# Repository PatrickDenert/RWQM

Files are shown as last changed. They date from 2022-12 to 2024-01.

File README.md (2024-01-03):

Abstract- Many water sources in the world are currently contaminated or at risk of
contamination. The purpose of this system is to allow for the remote monitoring of
water sources in order to preserve the health of many communities. Allowing remote
monitoring allows for faster results and constant monitoring of water quality.

For a full documentation of the project then you can read the Remote Water Quality Monotor report pdf listed in the repository.

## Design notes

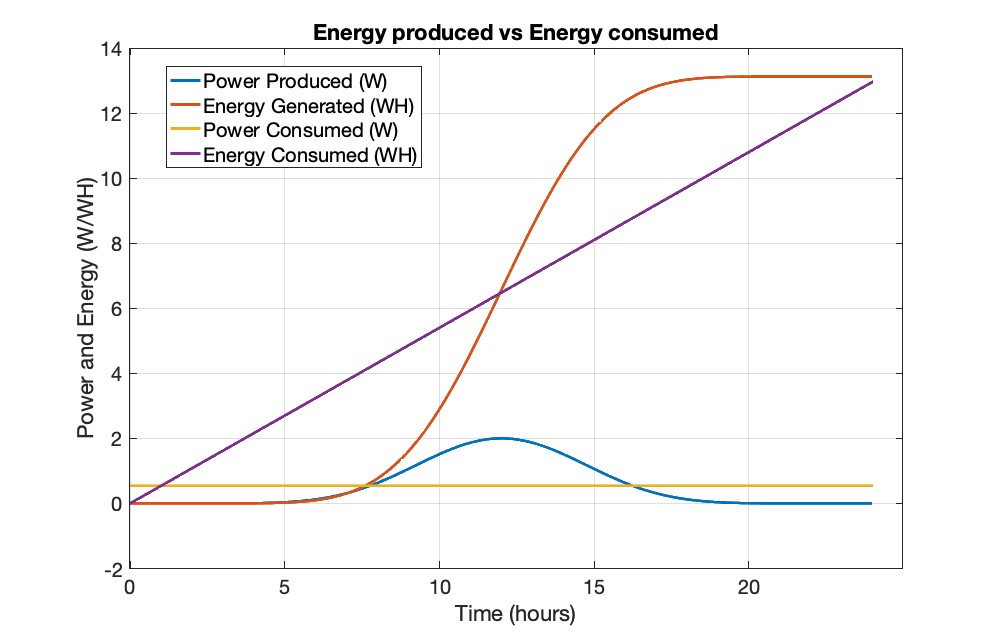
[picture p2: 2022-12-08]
assets/energy.jpg

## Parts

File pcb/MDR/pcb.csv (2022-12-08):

Source: | /Users/dave/Documents/school/sdp/pcb/MDR/pcb.kicad_sch
Date: | Thursday, November 10, 2022 at 03:40:49 PM
Tool: | Eeschema (6.0.7-1)-1
Generator: | /Applications/KiCad/KiCad.app/Contents/SharedSupport/plugins/bom_csv_grouped_by_value.py
Component Count: | 13
Individual Components:
Item | Qty | Reference(s) | Value | LibPart | Footprint | Datasheet
 |  | C1 | 0.1uF | Device:C | Capacitor_SMD:C_1206_3216Metric_Pad1.33x1.80mm_HandSolder | ~
 |  | C2 | 0.1uF | Device:C | Capacitor_SMD:C_1206_3216Metric_Pad1.33x1.80mm_HandSolder | ~
 |  | C3 | 0.1uF | Device:C | Capacitor_SMD:C_1206_3216Metric_Pad1.33x1.80mm_HandSolder | ~
 |  | C4 | 22pF | Device:C | Capacitor_SMD:C_1206_3216Metric_Pad1.33x1.80mm_HandSolder | ~
 |  | C5 | 22pF | Device:C | Capacitor_SMD:C_1206_3216Metric_Pad1.33x1.80mm_HandSolder | ~
 |  | J1 | 1x3f Tmp Sens | Connector:Conn_01x03_Male | Connector_PinSocket_2.54mm:PinSocket_1x03_P2.54mm_Vertical | ~
 |  | J2 | 1x4f Screen | Connector:Conn_01x04_Female | Connector_PinSocket_2.54mm:PinSocket_1x04_P2.54mm_Vertical | ~
 |  | J3 | 1x8f Digital Pin Headers | Connector:Conn_01x08_Female | Connector_PinSocket_2.54mm:PinSocket_1x08_P2.54mm_Vertical | ~
 |  | J4 | 1x2f LED | Connector:Conn_01x02_Female | Connector_PinHeader_2.54mm:PinHeader_1x02_P2.54mm_Vertical | ~
 |  | J5 | 1x3f tmp switch | Connector:Conn_01x03_Female | Connector_PinSocket_2.54mm:PinSocket_1x03_P2.54mm_Vertical | ~
 |  | J6 | 1x2F 5V in | Connector:Conn_01x02_Female | Connector_PinHeader_2.54mm:PinHeader_1x02_P2.54mm_Vertical | ~
 |  | U1 | ATmega328-P | MCU_Microchip_ATmega:ATmega328-P | Package_DIP:DIP-28_W7.62mm_Socket | http://ww1.microchip.com/downloads/en/DeviceDoc/ATmega328_P%20AVR%20MCU%20with%20picoPower%20Technology%20Data%20Sheet%2040001984A.pdf
 |  | Y1 | 16MHz | Device:Crystal | Crystal:Crystal_SMD_3225-4Pin_3.2x2.5mm | ~
Collated Components:
Item | Qty | Reference(s) | Value | LibPart | Footprint | Datasheet
1 | 3 | C1, C2, C3 | 0.1uF | Device:C | Capacitor_SMD:C_1206_3216Metric_Pad1.33x1.80mm_HandSolder | ~
2 | 2 | C4, C5 | 22pF | Device:C | Capacitor_SMD:C_1206_3216Metric_Pad1.33x1.80mm_HandSolder | ~
3 | 1 | J1 | 1x3f Tmp Sens | Connector:Conn_01x03_Male | Connector_PinSocket_2.54mm:PinSocket_1x03_P2.54mm_Vertical | ~
4 | 1 | J2 | 1x4f Screen | Connector:Conn_01x04_Female | Connector_PinSocket_2.54mm:PinSocket_1x04_P2.54mm_Vertical | ~
5 | 1 | J3 | 1x8f Digital Pin Headers | Connector:Conn_01x08_Female | Connector_PinSocket_2.54mm:PinSocket_1x08_P2.54mm_Vertical | ~
6 | 1 | J4 | 1x2f LED | Connector:Conn_01x02_Female | Connector_PinHeader_2.54mm:PinHeader_1x02_P2.54mm_Vertical | ~
7 | 1 | J5 | 1x3f tmp switch | Connector:Conn_01x03_Female | Connector_PinSocket_2.54mm:PinSocket_1x03_P2.54mm_Vertical | ~
8 | 1 | J6 | 1x2F 5V in | Connector:Conn_01x02_Female | Connector_PinHeader_2.54mm:PinHeader_1x02_P2.54mm_Vertical | ~
9 | 1 | U1 | ATmega328-P | MCU_Microchip_ATmega:ATmega328-P | Package_DIP:DIP-28_W7.62mm_Socket | http://ww1.microchip.com/downloads/en/DeviceDoc/ATmega328_P%20AVR%20MCU%20with%20picoPower%20Technology%20Data%20Sheet%2040001984A.pdf
10 | 1 | Y1 | 16MHz | Device:Crystal | Crystal:Crystal_SMD_3225-4Pin_3.2x2.5mm | ~

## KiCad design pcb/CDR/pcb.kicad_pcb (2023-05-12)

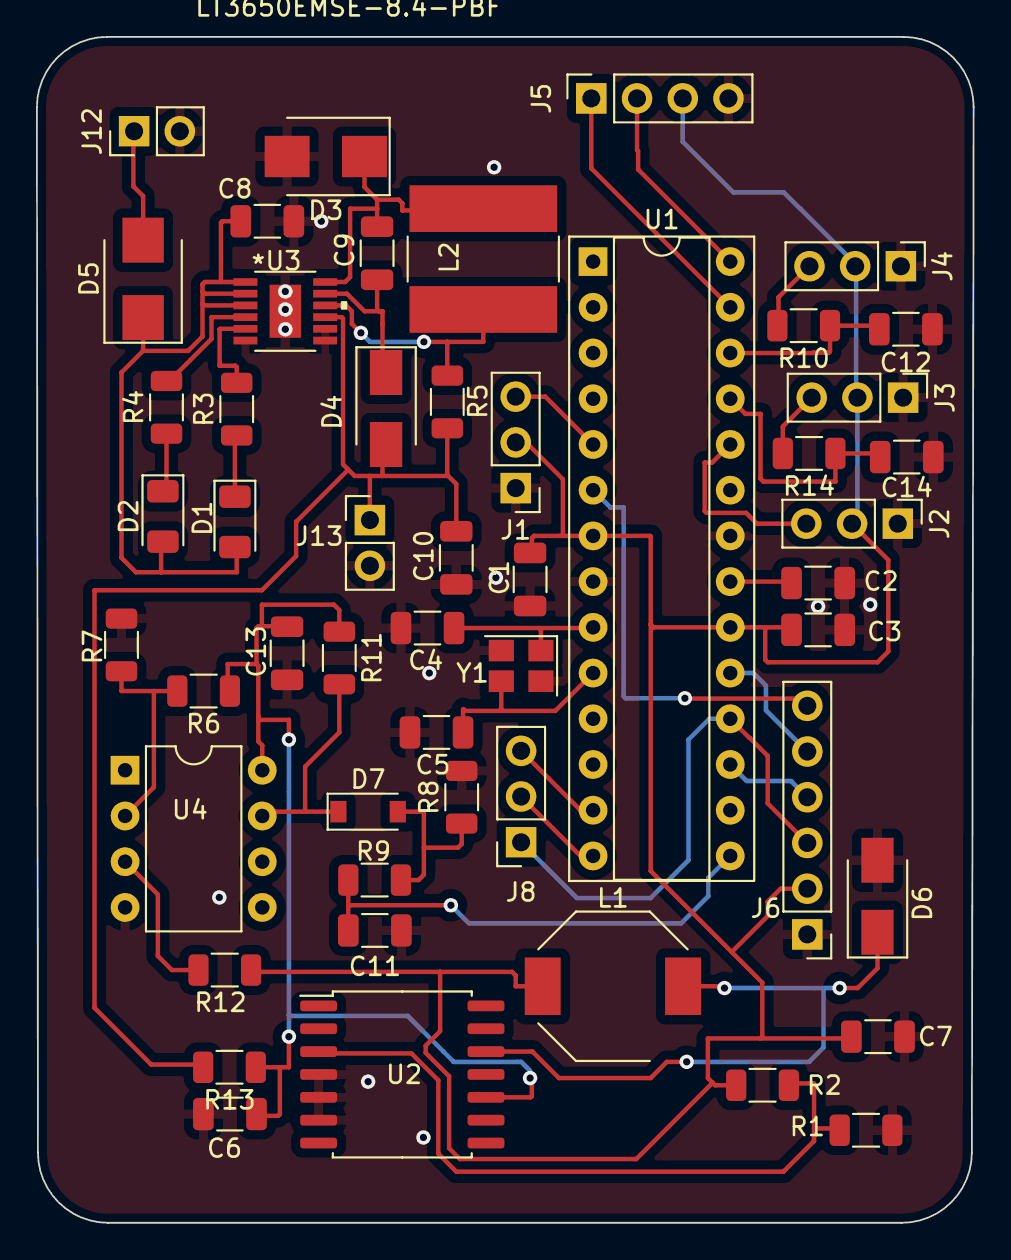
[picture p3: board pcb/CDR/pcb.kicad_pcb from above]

Board: 2 copper layers, 52.0 x 65.9 mm, 51 parts (0 on the bottom side), 37 nets.

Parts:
C1, C2, C3: 0.1uF; C_1206_3216Metric
C4, C5: 22pF; C_1206_3216Metric
C6: 22uF; C_1206_3216Metric
C7: 220uF; C_1206_3216Metric
C8, C10, C11, C12, C14: 10uF; C_1206_3216Metric
C9, C13: 1uF; C_1206_3216Metric
D1: Red; D_1206_3216Metric
D2: Green; D_1206_3216Metric
D3, D5: CMPSH3-40MA; D_SMB
D4: CMPSH1-4; D_SMA
D6: 11DQ06; D_SMA
D7: 1V; D_SOD-123
J1, J2, J3, J4: Conn_01x03_Male; PinHeader_1x03_P2.54mm_Vertical
J5: Conn_01x04_Female; PinSocket_1x04_P2.54mm_Vertical
J6: SD Card Reader; PinHeader_1x06_P2.54mm_Vertical
J8: cell data headers; PinSocket_1x03_P2.54mm_Vertical
J12: V Solar; PinHeader_1x02_P2.54mm_Vertical
J13: V batt; PinHeader_1x02_P2.54mm_Vertical
L1: 330 uH; L_Bourns-SRU8028_8.0x8.0mm
L2: 10uH; L_Bourns-SRN8040_8x8.15mm
R1: 1K; R_1206_3216Metric
R2: 3.1k; R_1206_3216Metric
R3, R4: 5.1k; R_1206_3216Metric
R5: 0.05; R_1206_3216Metric
R6: 100k; R_1206_3216Metric
R7: 220k; R_1206_3216Metric
R8: 50k; R_1206_3216Metric
R9: 160; R_1206_3216Metric
R10, R14: 0/160; R_1206_3216Metric
R11: 1k; R_1206_3216Metric
R12, R13: 0; R_1206_3216Metric
U1: ATmega328-P; DIP-28_W7.62mm_Socket
U2: LM2574HVM-12; SOIC-14W_7.5x9mm_P1.27mm
U3: LT3650EMSE-8.4-PBF
U4: LM311; DIP-8_W7.62mm
Y1: 16MHz; Crystal_SMD_TXC_7M-4Pin_3.2x2.5mm

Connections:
GND: C1.2, C2.2, C3.1, C4.1, C5.1, C6.2, C7.2, C8.2, C10.2, C11.2, C12.1, C13.1, C14.1, D3.2 (A), D6.2 (A), J1.1, J2.1, J3.1, J4.1, J5.4, J6.1, J12.2, J13.2, R1.1, R7.1, R8.2, U1.8 (GND), U1.22 (GND), U2.4 (SGND), U2.5 (~ON/OFF), U2.6 (PGND), U3.6 (TIMER), U3.7 (RNG/SS), U3.8 (NTC), U3.EPAD, U4.4 (V-), Y1.2, Y1.4
unnamed: C2.1, U1.21 (AREF)
unnamed: C4.2, U1.9 (XTAL1/PB6), Y1.1
unnamed: C5.2, U1.10 (XTAL2/PB7), Y1.3
unnamed: C8.1, D1.2 (A), D2.2 (A), D5.1 (K), U3.1 (VIN), U3.2 (CLP), U3.3 (*SHDN)
unnamed: C9.1, D3.1 (K), L2.2, U3.12 (SW)
unnamed: C9.2, D4.1 (K), U3.11 (BOOST)
unnamed: C10.1, D4.2 (A), J13.1, R5.2, R13.2, U3.9 (BAT)
unnamed: C11.1, R9.2, U1.15 (PB1)
unnamed: C12.2, R10.1, U1.26 (PC3)
unnamed: C6.1, C13.2, R6.1, R11.1, R13.1, U2.10 (VIN), U4.8 (V+)
unnamed: C14.2, R14.1, U1.25 (PC2)
unnamed: D1.1 (K), R3.1
unnamed: D2.1 (K), R4.1
unnamed: D5.2 (A), J12.1
unnamed: D6.1 (K), L1.1, U2.12 (OUT)
unnamed: D7.1 (K), R11.2, U4.7
unnamed: D7.2 (A), R8.1, R9.1
unnamed: J1.3, U1.5 (PD3)
unnamed: J2.3, U1.24 (PC1)
unnamed: J3.3, R14.2
unnamed: J4.3, R10.2
unnamed: J5.1, U1.27 (PC4)
unnamed: J5.2, U1.28 (PC5)
unnamed: J6.3, J8.1, U1.18 (PB4)
unnamed: J6.4, U1.17 (PB3)
unnamed: J6.5, U1.19 (PB5)
unnamed: J6.6, U1.6 (PD4)
unnamed: J8.2, U1.14 (PB0)
unnamed: J8.3, U1.13 (PD7)
unnamed: L2.1, R5.1, U3.10 (SENSE)
unnamed: R1.2, R2.2, U2.3 (FB)
unnamed: R3.2, U3.5 (*FAULT)
unnamed: R4.2, U3.4 (*CHRG)
unnamed: R6.2, R7.2, U4.2 (+)
unnamed: R12.1, U4.3 (-)
VCC: C1.1, C3.2, C7.1, J1.2, J2.2, J3.2, J4.2, J5.3, J6.2, L1.2, R2.1, R12.2, U1.7 (VCC), U1.20 (AVCC)

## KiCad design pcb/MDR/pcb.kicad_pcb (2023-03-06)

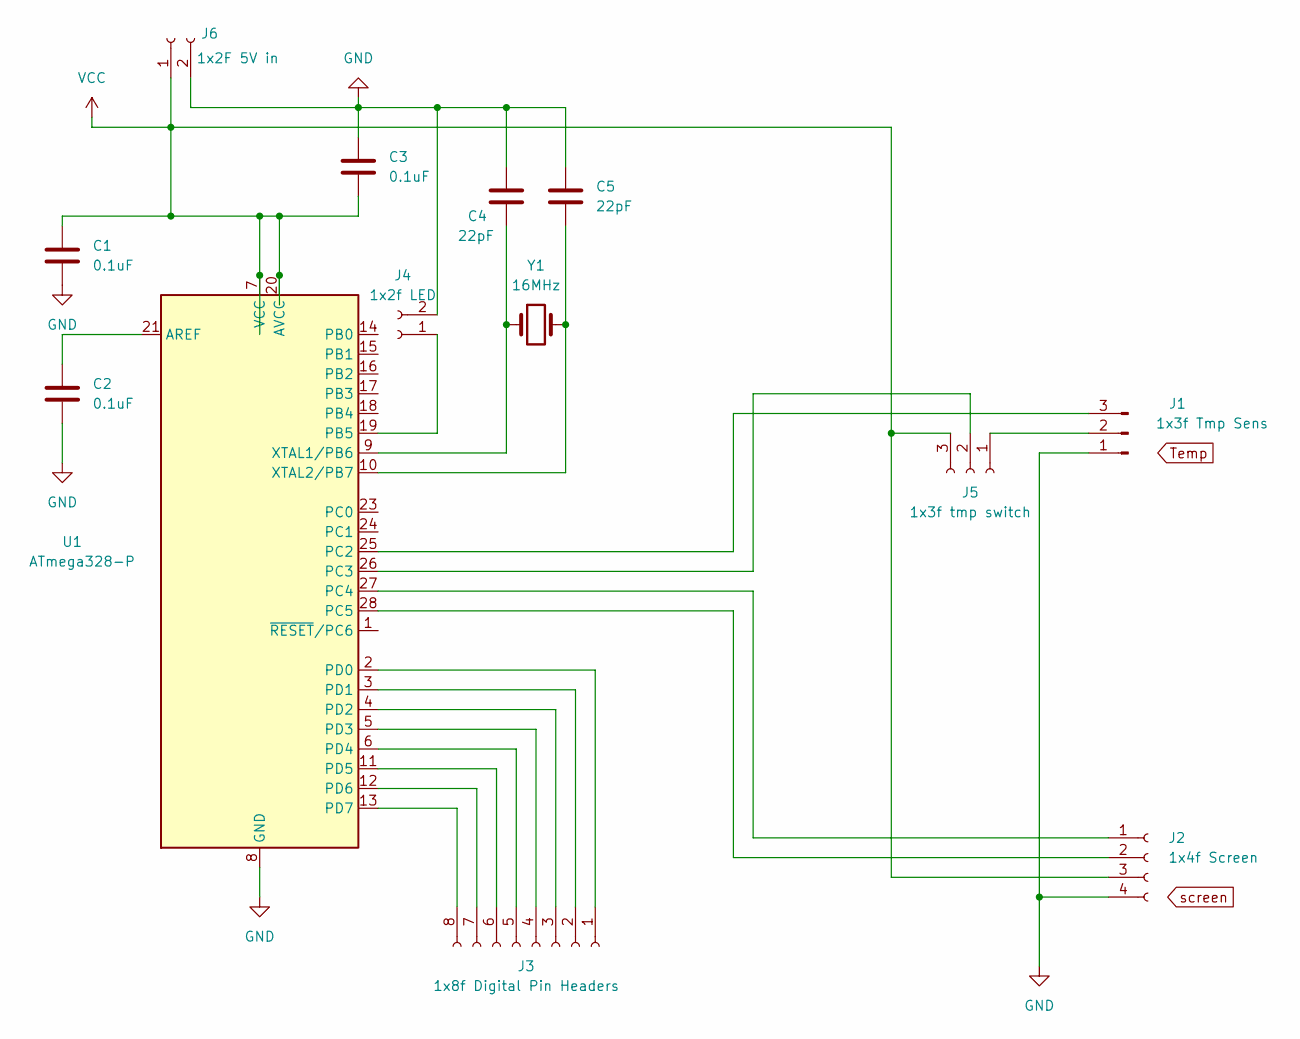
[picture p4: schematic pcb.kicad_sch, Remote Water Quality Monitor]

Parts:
C1, C2, C3: 0.1uF; C_1206_3216Metric
C4, C5: 22pF; C_1206_3216Metric
J1: 1x3f Tmp Sens; PinSocket_1x03_P2.54mm_Vertical
J2: 1x4f Screen; PinSocket_1x04_P2.54mm_Vertical
J3: 1x8f Digital Pin Headers; PinSocket_1x08_P2.54mm_Vertical
J4: 1x2f LED; PinHeader_1x02_P2.54mm_Vertical
J5: 1x3f tmp switch; PinSocket_1x03_P2.54mm_Vertical
J6: 1x2F 5V in; PinHeader_1x02_P2.54mm_Vertical
U1: ATmega328-P; DIP-28_W7.62mm_Socket
Y1: 16MHz; Crystal_SMD_3225-4Pin_3.2x2.5mm

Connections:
GND: C1.2, C2.2, C3.1, C4.1, C5.1, J1.1, J2.4, J4.2, J6.2, U1.8 (GND), U1.22 (GND)
unnamed: C2.1, U1.21 (AREF)
unnamed: C4.2, U1.9 (XTAL1/PB6), Y1.1
unnamed: C5.2, U1.10 (XTAL2/PB7), Y1.2
unnamed: J1.2, J5.1
unnamed: J2.1, U1.27 (PC4)
unnamed: J2.2, U1.28 (PC5)
unnamed: J3.1, U1.2 (PD0)
unnamed: J3.2, U1.3 (PD1)
unnamed: J3.3, U1.4 (PD2)
unnamed: J3.4, U1.5 (PD3)
unnamed: J3.5, U1.6 (PD4)
unnamed: J3.6, U1.11 (PD5)
unnamed: J3.7, U1.12 (PD6)
unnamed: J3.8, U1.13 (PD7)
unnamed: J4.1, U1.19 (PB5)
unnamed: J1.3, U1.25 (PC2)
unnamed: J5.2, U1.26 (PC3)
VCC: C1.1, C3.2, J2.3, J5.3, J6.1, U1.7 (VCC), U1.20 (AVCC)

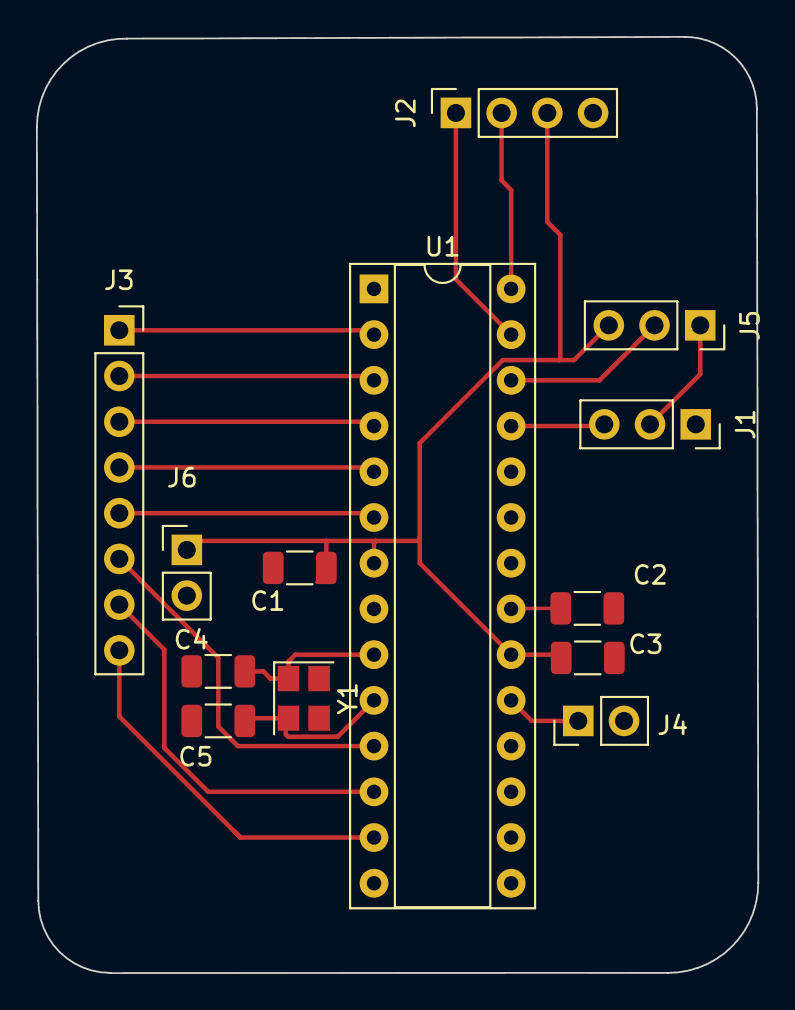
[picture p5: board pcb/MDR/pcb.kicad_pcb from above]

Board: 2 copper layers, 40.1 x 52.0 mm, 13 parts (0 on the bottom side), 19 nets.

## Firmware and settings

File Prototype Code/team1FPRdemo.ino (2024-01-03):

#include <DFRobot_SIM7000.h>
#include <Base64.h>
#include <OneWire.h>
#include "OneWire.h"
#include <SPI.h>
#include <SD.h>
#include <SoftwareSerial.h>
#include <stdlib.h>     /* strtoul */

#define PIN_TX     11
#define PIN_RX     10
SoftwareSerial     mySerial(PIN_RX,PIN_TX);
DFRobot_SIM7000    sim7000(&mySerial);

OneWire ds(3);

static char        buff[1500];  //response buffer for http requests

unsigned long long time;
float averageVoltage = 0,tdsValue = 0;
volatile double flow;
volatile double flowCalc;       //store flow when sensors are read and convert reading

float temp;
float tds;
float tb;
float cdt;

int inputStringLength;
int encodedLen;
int count = 0;

bool reconnect = false;
bool connection;                //determine if mcu cellular is working (ie toggle sd module)

char payloadBuffer[300];

char *ret;
char buff2[22];
const char unixtime[9] = "unixtime";

unsigned long long getTime(){
  Serial.println("time setup");
  int count3 = 0;
  while(1){
    count3 = count3 + 1;                              
    Serial.println(count3);
    Serial.println(F("Turn ON SIM7000......"));
    if(sim7000.turnON()){                             //Turn ON SIM7000
      Serial.println(F("Successfully turned on"));
      connection = true;
      break;
    } else {
      Serial.println(F("Failed to turn on!"));
      connection = false;
      delay(1000);
    }
    if(count3 == 3){                                 //try to connect to cellular 3 times before switching to offline mode
      reconnect = true;
      break;
    }
   
   }
  
  if(connection == true){
    if(sim7000.setBaudRate(19200)){                  //Set SIM7000 baud rate from 115200 to 19200 reduce the baud rate to avoid distortion
      Serial.println(F("Set baud rate:19200"));
      connection = true;
      }else{
        Serial.println(F("Failed to set baud rate"));
        connection = false;
        delay(1000);
      }
  }
  while(connection == true){
     if(sim7000.attacthService()){
        Serial.println(F("Attatched to Service"));
        connection = true;
        break;
     } else {
        Serial.println(F("Fail to Attatch to service"));
      connection = false;
     }
  }

  delay(200);
  if(connection == true){
  Serial.println("Connecting......");
  if (sim7000.openNetwork(sim7000.eTCP, "worldtimeapi.org", 80)) {  //Start Up TCP or UDP Connection to time api
    Serial.println("Connect OK");
  } else {
    Serial.println("Fail to connect");
    while (1);
  }
  sim7000.send("GET http://worldtimeapi.org/api/timezone/America/New_York HTTP/1.1\r\nAccept:application/json\r\nHost:worldtimeapi.org\r\n\r\n");    //Send Data Through TCP or UDP Connection GET /api/timezone/America/New_York HTTP/1.0
  int dataNum = sim7000.recv(buff, 1500);                           //Receive data
  delay(500);
  
  ret = strstr(buff, unixtime);                                     //remove response headers from buffer
  sprintf(buff2,"%s\n", ret);
  
  delay(1000);
  char buff3[11];
  
  char subString[20];

  sprintf(buff3,"%s", getSubString(buff2,                           //extract unixtime from json response
        subString, 10, 10));
        
  time = strtoul(buff3,NULL,10);                                    //convert str to unsigned long
  
  if (sim7000.closeNetwork()) {                                     //End the connection
    delay(1000);
    Serial.println("Close connection");
  } else {
    Serial.println("Fail to close connection");
  }
  delay(1000);
  Serial.println(F("Turn OFF SIM7000......"));
  delay(1000);
  
  if(sim7000.turnOFF()){                                            //Turn ON SIM7000
    Serial.println(F("Successfully turned off"));
    delay(1000);
    connection = true;
  } else {
    Serial.println(F("Failed to turn off!"));
    connection = false;
  }                                                                 //Turn OFF SIM7000
  }
  time = time * 1000;                                               //convert seconds to milliseconds
  time = time - 14400000;                                           //convert time zone from est to gmt

  return time;
  
}


void pulse(){                                                       //measure the quantity of square wave from flow sensor
  flow += 1.0 / 450.0;
}

char* getSubString(char* inputString, char* subString,              //get substring from inputs (used to extract unix time)
    int index, int subStringLength){  
    int counter, inputStringLength = strlen(inputString);    
 
    if(index < 0 || index > inputStringLength || 
          (index + subStringLength) > inputStringLength){
        printf("Invalid Input");
        return NULL;
    }
    for(counter = 0; counter < subStringLength; counter++){
        subString[counter] = inputString[index++];
    }
    subString[counter] = '\0';
     
    return subString;
}

void setup() {
  SD.begin(0);                        //init chipselect of SD module
             
  pinMode(14,INPUT);                  //low battery circuit input
  attachInterrupt(2, pulse, RISING);  //DIGITAL Pin 2: Interrupt 0

  pinMode(A1,INPUT);                  //input for tds sensor
  
  Serial.begin(9600);                 
  mySerial.begin(19200);              //serial to cell module
  
  time = getTime();                   //get time from api
  delay(1000);
}



void loop() {
  delay(1000);
  if(reconnect == true){              //check if system was previously disconnected from cellular and update time
    time = getTime();
    reconnect = false;
  }
    flow = 0.0;
    //-------------------------------//
    //------ initialize sim7000 -----//
    //-------------------------------//
  
  Serial.println("--main loop--");
  int count2 = 0;
  while(1){
    count2 = count2 + 1;
    Serial.println(count2);
    Serial.println(F("Turn ON SIM7000......"));
    if(sim7000.turnON()){                             //Turn ON SIM7000
      Serial.println(F("Successfully turned on"));
      connection = true;
      break;
    } else {
      Serial.println(F("Failed to turn on!"));
      connection = false;
      delay(1000);
    }
    if(count2 == 3){                                  //try 3 times to connect to cellular and go in offline mode if not
      break;
    }
   
   }
  
  if(connection == true){
    if(sim7000.setBaudRate(19200)){                  //Set SIM7000 baud rate from 115200 to 19200 reduce the baud rate to avoid distortion
      Serial.println(F("Set baud rate:19200"));
      connection = true;
      }else{
        Serial.println(F("Failed to set baud rate"));
        connection = false;
        delay(1000);
      }
  }
  if(connection == true){                                 //attach to cellular service
     if(sim7000.attacthService()){
        Serial.println(F("Attached to Service"));
        connection = true;
     } else {
        Serial.println(F("Fail to Attach to service"));
      connection = false;
     }
  }

  //-------------------------------//
  //-------- Read Sensors ---------//
  //-------------------------------//
  temp = 0.0;                                 //reset sensor readings
  tds = 0.0;
  tb = 0.0;
  cdt = 0.0;
  
  flowCalc = getFlow();                       
    
  time += 45000;                              //update time locally to reduce connections to server when not needed
  //time = getTime();                         //update time if needed
  
  temp = getTemp();
  tds = getTDS(temp);
  tb = getTurbidity();   
  cdt = tds*2.0;                              //cdt calculation
  temp = temp*1.8 + 32;                       //celsius to Fahrenheit
  bool battery = getBattLevel();              //check for low battery
  
 
  //-------------------------------//
  //------ format String ----------//
  //-------------------------------//

  
  JSONdotStringify();                         //turn sensor values into json string 
  //Serial.println(payloadBuffer);

  if(connection == false){                    //if connection false save to sd card
    SDCardWrite(payloadBuffer);
    SDCardRead();
    reconnect = true;                         //set true to try to restart system next loop

    delay(10000);  
  }

  else{

    //-------------------------------//
    //----- Create valid Message ----//
    //-------------------------------//

    inputStringLength = strlen(payloadBuffer);
    encodedLen = Base64.encodedLength(inputStringLength);

    char base64String[encodedLen+1];
    char message[encodedLen+35];
    
    Base64.encode(base64String, payloadBuffer, inputStringLength);                      //base64encode string before sending to server
    
    sprintf(message, "{\"k\":\"5#p7ILQi\",\"d\":\"%s\",\"t\":\"test\"}", base64String); //create message json string before sending to cellular

    //-------------------------------//
    //------- Send Message ----------//
    //-------------------------------//

    sendmsg(message);
    Serial.flush();

    //-------------------------------//
    //------ Send Error Code --------//
    //-------------------------------//

    byte error_code = alert(tds,temp,tb,cdt,battery);               //generate error code
    Serial.print("error code: ");

    Serial.println(error_code);

    if(error_code !=0 ){                                            //if error detected send to server and email
      char * alertmessage;
      alertmessage = (char*) malloc(100);
      sprintf(alertmessage, "{\"k\":\"5#p7ILQi\",\"d\":\"%i\",\"t\":\"alert\"}", error_code);

      delay(1000);
      sendmsg(alertmessage);
      delay(1000);

      free(alertmessage);
    }
  }

  //-------------------------------//
  //------ Turn off sim7000 -------//
  //-------------------------------//

  count++;
  Serial.print("loop number ");
  Serial.println(count);
  Serial.println(" ended");

  if(connection == true){
  Serial.println(F("Turn OFF SIM7000......"));
  delay(1000);
  if(sim7000.turnOFF()){                                                        //Turn ON SIM7000
    Serial.println(F("Successfully turned off"));
    delay(1000);
    connection = true;
  } else {
    Serial.println(F("Failed to turn off!"));
    connection = false;
    delay(1000);
  }
  }
  delay(1000);

}



bool sendmsg(char *message){                                                    //send message to hologram cloud which sends it to server
  if(sim7000.openNetwork(sim7000.eTCP, "cloudsocket.hologram.io", 9999)){
    Serial.println(F("Connect OK"));
  } else {
    Serial.println(F("Fail to connect"));
    return false;
  }
  delay(1000);
  if(sim7000.send(message)){
    Serial.println(F("Sent OK"));
    delay(1000);
  } else {
    Serial.println(F("Fail to send"));
    return false;
   
  }
  sim7000.closeNetwork();
  return true;
}



char *ulltoa(uint64_t value, char *buf, int radix) {                              //unsigned long to char
    char tmp[64 + 1];
    char *p1 = tmp, *p2;
    static const char xlat[] = "0123456789ABCDEFGHIJKLMNOPQRSTUVWXYZ";
    if(radix < 2 || radix > 36)    return nullptr;
    do {*p1++ = xlat[value % (unsigned)radix];} while((value /= (unsigned)radix));
    for(p2 = buf; p1 != tmp; *p2++ = *--p1) ;
    *p2 = '\0';
    return buf;
}

bool JSONdotStringify(){                                                          //convert readings and generate json string
  char timeString[16];
  ulltoa(time, timeString, 10);

  char tempString[7];
  dtostrf(temp, 6, 2, tempString);

  char flowString[6];
  dtostrf(flow, 5, 2, flowString);

  char cdtString[8];
  dtostrf(cdt, 7, 2, cdtString);

  char tbString[8];
  dtostrf(tb, 7, 2, tbString);

  char tdsString[8];
  dtostrf(tds, 7, 2, tdsString);

  sprintf(payloadBuffer, "{\"time\":%s,\"temp\":%s,\"flow\":%s,\"cdt\":%s,\"tb\":%s,\"tds\":%s}", timeString, tempString, flowString, cdtString, tbString, tdsString);

  return true;
}

int availableMemory() {                                                  //check memory of mcu (debugging purposes)
  int size = 16000;
  byte *buf;
  while ((buf = (byte *) malloc(--size)) == NULL);
  free(buf);
  return size;
}

byte alert(float tds, float temp, float tb, float cdt,byte battery){     //error code generator
  byte error_code = B00000;
  if(battery == false){
    error_code = error_code | B10000;
  }
  if((tb * 1.073) > 5){
      error_code = error_code | B01000;
  }
  if((temp * 1.005) > 104 | (temp * 1.005) < 32){
    error_code = error_code | B00100;
  }

  if((tds * 1.1) > 500){
    error_code = error_code | B00010;
  }

  if((cdt * 1.073) > 1000){
    error_code = error_code | B00001;
  }

  return error_code;
}

void SDCardWrite(char *payload) {
    File file = SD.open("reading.txt", FILE_WRITE);

  // if the file opened okay, write to it:
  if (file) {
    file.println(payload);
    // close the file:
    file.close();
  } else {
    // if the file didn't open, print an error:
    Serial.println("error opening reading.txt");
  }
 
}

void SDCardRead() {                                   //print data in sd card file
  File file = SD.open("reading.txt");
  if (file) {
    //Serial.println("test.txt:");

    // read from the file until there's nothing else in it:
    while (file.available()) {
      Serial.write(file.read());
    }
    // close the file:
    file.close();
    Serial.println(F("--- end of file ---"));
  } else {
    // if the file didn't open, print an error:
    Serial.println("error opening test.txt");
  }
}

float getTDS(float temperature){                          //get tds reading from sensor
   int sensorvalue = analogRead(A1);
   
    float volt = sensorvalue * (float)5.0 / 1024.0;
    float compensationCoefficient=1.0+0.02*(temperature-25.0);
    float compensationVolatge=volt/compensationCoefficient;  //temperature compensation
    tdsValue=(133.42*compensationVolatge*compensationVolatge*compensationVolatge - 255.86*compensationVolatge*compensationVolatge + 857.39*compensationVolatge)*0.5;
  
    return tdsValue * (2.0/3.0);
   
}

float getTurbidity(){
  int sensorValue = analogRead(A0);                         // read the input on analog pin 0:
  float volt = sensorValue * (5.0 / 1023.0);                // Convert the analog reading (which goes from 0 - 1023) to a voltage (0 - 5V):
  
  if(volt < 2.5){
    return 3000;
  }
  if(volt > 4.2){
    return 0;
  }
  else{
    float turbidity = -1120.4*square(volt) + 5742.3*volt - 4352.9;    //convert voltage to turbidity value
    return turbidity;
  }

}
float getTemp(){
  //returns the temperature from one DS18S20 in DEG Celsius

  byte data[12];
  byte addr[8];

  if ( !ds.search(addr)) {        //get address of ds18b20
      //no more sensors on chain, reset search
      ds.reset_search();
      return -1000;
  }

  if ( OneWire::crc8( addr, 7) != addr[7]) {    //get crc
      Serial.println("CRC is not valid!");
      return -1000;
  }

  if ( addr[0] != 0x10 && addr[0] != 0x28) {
      Serial.print("Device is not recognized");
      return -1000;
  }

  ds.reset();
  ds.select(addr);                              //choose correct temperature sensor
  ds.write(0x44,1);                             // start conversion, with parasite power on at the end

  byte present = ds.reset();                    //1 = device is present
  ds.select(addr);                              //choose correct temperature sensor
  ds.write(0xBE);                               // Read Scratchpad and crc


  for (int i = 0; i < 9; i++) {                 // we need 9 bytes
    data[i] = ds.read();
  }

  ds.reset_search();                            //reset between searches

  byte MSB = data[1];                           // msb of temp measuremtn
  byte LSB = data[0];                           //lsb of temp measurement

  float tempRead = ((MSB << 8) | LSB);          //using two's compliment //co,bine 2 numbers into 1
  float TemperatureSum = tempRead / 16;         //convert temp reading

  return TemperatureSum;

}

volatile double getFlow(){
  flowCalc = flow * 4;                           //convert L/h to L/15s to ensure correct flow is sent
  return flowCalc;
}

bool getBattLevel(){                             //read input of low battery circuit
  int x = digitalRead(14);
  if (x == 0) {
    return true;
  } else {
    return false;
  }
}

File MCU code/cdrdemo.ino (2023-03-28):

#include <OneWire.h>
#include <tinyECC.h>
#include <ArduinoJson.h>
#include <FastCRC.h>
#include <SPI.h>
#include <SD.h>

//#define TbSensorPin A0
//#define TdsSensorPin A1
#define VREF 5.0      // analog reference voltage(Volt) of the ADC
#define SCOUNT  30           // sum of sample point
int analogBuffer[SCOUNT];    // store the analog value in the array, read from ADC
int analogBufferTemp[SCOUNT];
int analogBufferIndex = 0,copyIndex = 0;
float averageVoltage = 0,tdsValue = 0;
//int DS18S20_Pin = 2; //DS18S20 Signal pin on digital 2
volatile double flow;
//char messageBuffer[96];
int connection = 0;    //set to 1 if conneted to server (used to toggle SD card)

class CrcWriter {               //class given by json library to hash json
public:
  CrcWriter() {
    _hash = _hasher.crc32(NULL, 0);
  }

  size_t write(uint8_t c) {
    _hash = _hasher.crc32_upd(&c, 1);
  }

  size_t write(const uint8_t *buffer, size_t length) {
    _hash = _hasher.crc32_upd(buffer, length);
  }

  uint32_t hash() const {
    return _hash;
  }

private:
  FastCRC32 _hasher;
  uint32_t _hash;
};


//Temperature chip i/o
OneWire ds(2);  // on digital pin 2one

void setup(void) {
  Serial.begin(9600);                 //set baudrate
  pinMode(A1,INPUT);                  //tds sensor
  flow = 0;
  attachInterrupt(1, pulse, RISING);  //set interrupt pin to d3, call pulse() on interrupt, call interrupt when pin goes L->H
  pinMode(7,INPUT);
  
  SD.begin(4);
  while (!Serial) {
    ; // wait for serial port to connect. Needed for native USB port only
  }

  if (!SD.begin(4)) {
    Serial.println(F("SD Card initialization failed!"));
    
  }
  Serial.println(F("SD Card initialization done."));
}

void loop(void) {
  float temp = 0;
  float tb = 0;
  float tds = 0;

  StaticJsonDocument<200> doc;
  
  for(int i = 0; i<100; i++){                //take lots of samples of measurements
    temp = temp + getTemp();
    tb = tb + getTurbidity();
    tds = tds + getTDS2(temp/(i));
  }

  //temp = getTemp();
  //tb = tb + getTurbidity();
  //tds = tds + getTDS2(temp);
  
  temp = temp/100;            //get avg temp measuremnt
  tb = tb/100;                //get avg turbidiy measuremnt
  tds = tds/100;                            //get avg tds measurement
  float cdt = tds*2;
  temp = temp*1.8 + 32;

  doc["temp"] = temp;         //add parammeters to json file
  doc["tb"] = tb;
  doc["tds"] = tds;
  doc["cdt"] = cdt;
  
  Serial.println(F("--------------------------------"));
  //String payload = "temperature: " + String(temp) + " Celsius" + " Farenheight" + "\nturbidity" + String(tb) + " NTU" + "\nTDS: " + String(tds) + " ppm" + "\nConductivity: " + String(cdt) + " us/cm" + "\nWaterflow: " + String(flow) + " L/s";
  //Serial.println(payload);

  
  byte error_code = alert(tds,temp,tb,cdt);    //get error code
  Serial.println(String(error_code,BIN));

  //doc["error code"] = String(error_code,BIN);

  //Serial.println(error_code,BIN);

  //serializeJsonPretty(doc, Serial);
  serializeJson(doc,Serial);

  /* CrcWriter writer;
  serializeJson(doc, writer);
  Serial.println(writer.hash());              //hash json file

  tinyECC e;                                  
  e.plaintext = writer.hash();
  e.encrypt();                                //encrypt hash
  Serial.println(e.ciphertext);     

  e.decrypt();
  Serial.println(e.plaintext);
 */
 
  //if (connection){
  
  //}
  File dataFile = SD.open("datalog.txt", FILE_WRITE);

  // if the file is available, write to it:
  if (dataFile) {
    //dataFile.println("{\"temp\":77.7875,\"tb\":1962.658,\"tds\":34.00633,\"cdt\":68.01266}");
    dataFile.println("payload");
    dataFile.close();
    Serial.println("SD Write Succesful");
    // print to the serial port too:
  }
  // if the file isn't open, pop up an error:
  else {
    Serial.println("error opening datalog.txt");
  }

  

  delay(5000);  //pause arduino
}



float alert(float tds, float temp, float tb, float cdt){     //error code generator
  byte error_code = B0000;
  if((tds * 1.1) > 500){
    Serial.println("Warning: tds levels past maximum limit!");
    error_code = error_code | B1000;
    
  }

  if((temp * 1.005) > 40 | (temp * 1.005) < 0){
    Serial.println("Warning: temperature outside safe limit!");
    error_code = error_code | B0100;

  }

  if((tb * 1.073) > 1){
    Serial.println("Warning: turbidity past maximum limit!");
    error_code = error_code | B0010;
    
  }

  if((cdt * 1.073) > 1000){
    Serial.println("Warning: conductivity past maximum limit!");
    error_code = error_code | B0001;
    
  }
  if (error_code == 0){
    Serial.println("All metrics within safe values");
  }
  return error_code;
  }

/*
float getTDS(float temperature){
  static unsigned long analogSampleTimepoint = millis();
   if(millis()-analogSampleTimepoint > 40U)     //every 40 milliseconds,read the analog value from the ADC
   {
     analogSampleTimepoint = millis();
     analogBuffer[analogBufferIndex] = analogRead(A1);    //read the analog value and store into the buffer
     analogBufferIndex++;
     if(analogBufferIndex == SCOUNT) 
         analogBufferIndex = 0;
   }
   static unsigned long printTimepoint = millis();
   if(millis()-printTimepoint > 800U)
   {
      printTimepoint = millis();
      for(copyIndex=0;copyIndex<SCOUNT;copyIndex++)
        analogBufferTemp[copyIndex]= analogBuffer[copyIndex];
      averageVoltage = getMedianNum(analogBufferTemp,SCOUNT) * (float)VREF / 1024.0; // read the analog value more stable by the median filtering algorithm, and convert to voltage value
      float compensationCoefficient=1.0+0.02*(temperature-25.0);    //temperature compensation formula: fFinalResult(25^C) = fFinalResult(current)/(1.0+0.02*(fTP-25.0));
      float compensationVolatge=averageVoltage/compensationCoefficient;  //temperature compensation
      tdsValue=(133.42*compensationVolatge*compensationVolatge*compensationVolatge - 255.86*compensationVolatge*compensationVolatge + 857.39*compensationVolatge)*0.5; //convert voltage value to tds value
   }
   return tdsValue;   
  
  
}

*/
float getTurbidity(){
  int sensorValue = analogRead(A0);// read the input on analog pin 0:
  float volt = sensorValue * (5.0 / 1024.0); // Convert the analog reading (which goes from 0 - 1023) to a voltage (0 - 5V):
  //Serial.println(volt);
  if(volt < 2.5){
    return 3000;
  }
  if(volt > 4.2){
    return 0;
  }
  else{
    float turbidity = -1120.4*square(volt) + 5742.3*volt - 4352.9;
    return turbidity;
  }

}
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

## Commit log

2022-10-31 initial pcb
    [pcb.kicad_pcb, pcb.kicad_sch]
2022-11-08 fix sensor data requst url
2022-11-09 pcb update
    [pcb.kicad_pcb, pcb.kicad_sch]
2022-12-08 fixed the app
    [pcb-B_Cu.gbr, pcb-B_Mask.gbr, pcb-B_Paste.gbr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]
2023-03-06 cdr pcb
    [pcb.kicad_pcb, pcb.kicad_sch]
2023-03-06 pcb and analytics updates
    [pcb.kicad_pcb]
2023-03-06 decoupling cap on lm 311
    [pcb.kicad_pcb, pcb.kicad_sch]
2023-03-17 major updates to interface, analytics and security
    [pcb-B_Cu.gbr, pcb-B_Mask.gbr, pcb-B_Paste.gbr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]
2023-03-20 Update cdr.ino
    fixed error code generation and hash and encryption
    [cdr.ino]
2023-03-23 readings from arduino show up in database and charts
2023-04-25 Create endtoend.ino
    sends error code and sensor data from actual sensors but there is an error atm where it stops after 1 loop
    [endtoend.ino]
2023-05-12 recent changes
    [pcb-B_Cu.gbr, pcb-B_Mask.gbr, pcb-B_Paste.gbr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]

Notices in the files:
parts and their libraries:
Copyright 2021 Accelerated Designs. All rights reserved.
